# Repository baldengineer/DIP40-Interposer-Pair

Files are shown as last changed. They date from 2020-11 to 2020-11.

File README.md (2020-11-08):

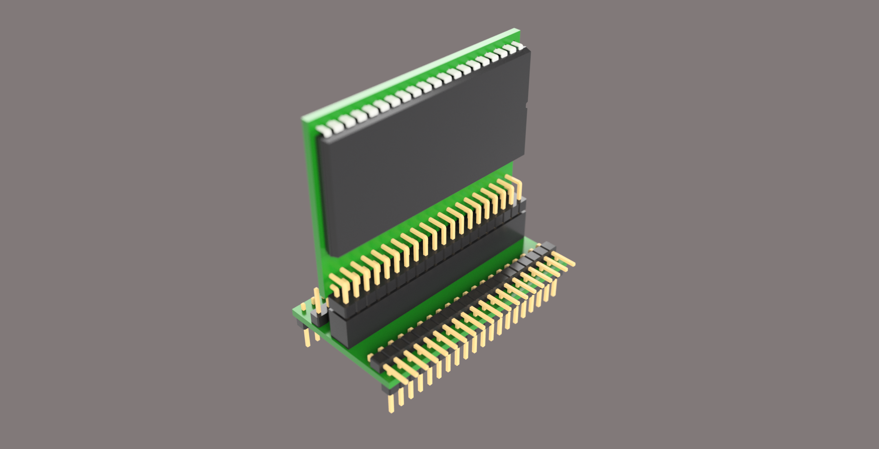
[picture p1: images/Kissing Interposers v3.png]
DIP40 interposer boards connected together

## DIP40 Interposer Board Pair
This adapter makes it easier to probe a DIP-40 (0.6" wide) chip using a logic analyzer or mixed-signal oscilloscope. The boards breakout each of the signals.

Originally this was designed to test the Z80 and ULA chips of a ZX-81. However, there is nothing chip-specific in this design.

Currently, the boards are untested and being manufactured.

## PCB-Side Board
This board plugs into the PCB or the socket on the PCB. It should have a 02x20 pin-socket in the middle facing "up". Two pin-headers go near the outside edges.

The rendered image shows right-angle and straight connectors. It is not clear yet which is a better option. Consider how your probes connect to the pins.

## Chip Carrier Board
The chip under test plugs into this board. Ideally, you probably want to use a socket to connect a 0.6" wide DIP-40 chip. Right-angled pin-headers allow for a clean mating. If you use "straight" header-pins, half of the logic probe pins are blocked.

## Bald Engineer on Twitch
This board was designed, built, and tested live with the Bald Engineer. Check out his electronics live stream at: [https://twitch.tv/baldengineer](https://twitch.tv/baldengineer).

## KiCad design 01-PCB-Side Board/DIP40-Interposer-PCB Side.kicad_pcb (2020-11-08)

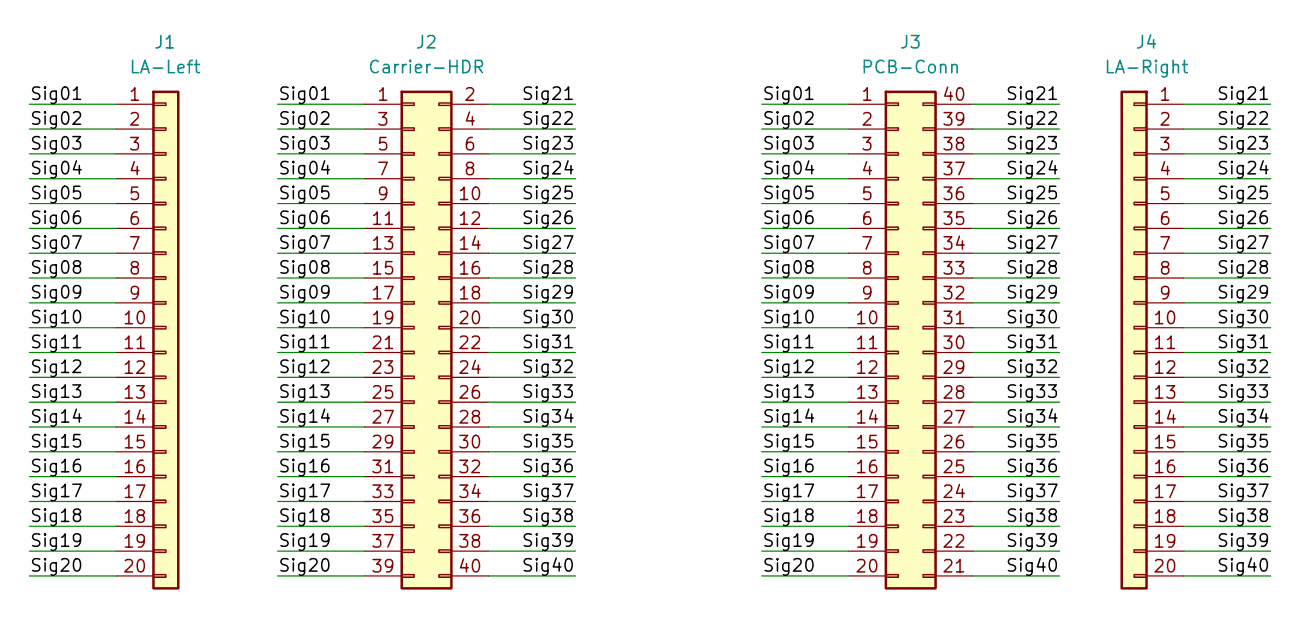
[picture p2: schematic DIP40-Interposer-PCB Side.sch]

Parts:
J1: LA-Left; PinHeader_1x20_P2.54mm_Vertical
J2: Carrier-HDR; PinSocket_2x20_P2.54mm_Vertical
J3: PCB-Conn; DIP-40_W25.4mm_Socket_LongPads
J4: LA-Right; PinHeader_1x20_P2.54mm_Vertical

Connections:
/Sig01: J1.1, J2.1, J3.1
/Sig02: J1.2, J2.3, J3.2
/Sig03: J1.3, J2.5, J3.3
/Sig04: J1.4, J2.7, J3.4
/Sig05: J1.5, J2.9, J3.5
/Sig06: J1.6, J2.11, J3.6
/Sig07: J1.7, J2.13, J3.7
/Sig08: J1.8, J2.15, J3.8
/Sig09: J1.9, J2.17, J3.9
/Sig10: J1.10, J2.19, J3.10
/Sig11: J1.11, J2.21, J3.11
/Sig12: J1.12, J2.23, J3.12
/Sig13: J1.13, J2.25, J3.13
/Sig14: J1.14, J2.27, J3.14
/Sig15: J1.15, J2.29, J3.15
/Sig16: J1.16, J2.31, J3.16
/Sig17: J1.17, J2.33, J3.17
/Sig18: J1.18, J2.35, J3.18
/Sig19: J1.19, J2.37, J3.19
/Sig20: J1.20, J2.39, J3.20
/Sig21: J2.2, J3.40, J4.1
/Sig22: J2.4, J3.39, J4.2
/Sig23: J2.6, J3.38, J4.3
/Sig24: J2.8, J3.37, J4.4
/Sig25: J2.10, J3.36, J4.5
/Sig26: J2.12, J3.35, J4.6
/Sig27: J2.14, J3.34, J4.7
/Sig28: J2.16, J3.33, J4.8
/Sig29: J2.18, J3.32, J4.9
/Sig30: J2.20, J3.31, J4.10
/Sig31: J2.22, J3.30, J4.11
/Sig32: J2.24, J3.29, J4.12
/Sig33: J2.26, J3.28, J4.13
/Sig34: J2.28, J3.27, J4.14
/Sig35: J2.30, J3.26, J4.15
/Sig36: J2.32, J3.25, J4.16
/Sig37: J2.34, J3.24, J4.17
/Sig38: J2.36, J3.23, J4.18
/Sig39: J2.38, J3.22, J4.19
/Sig40: J2.40, J3.21, J4.20

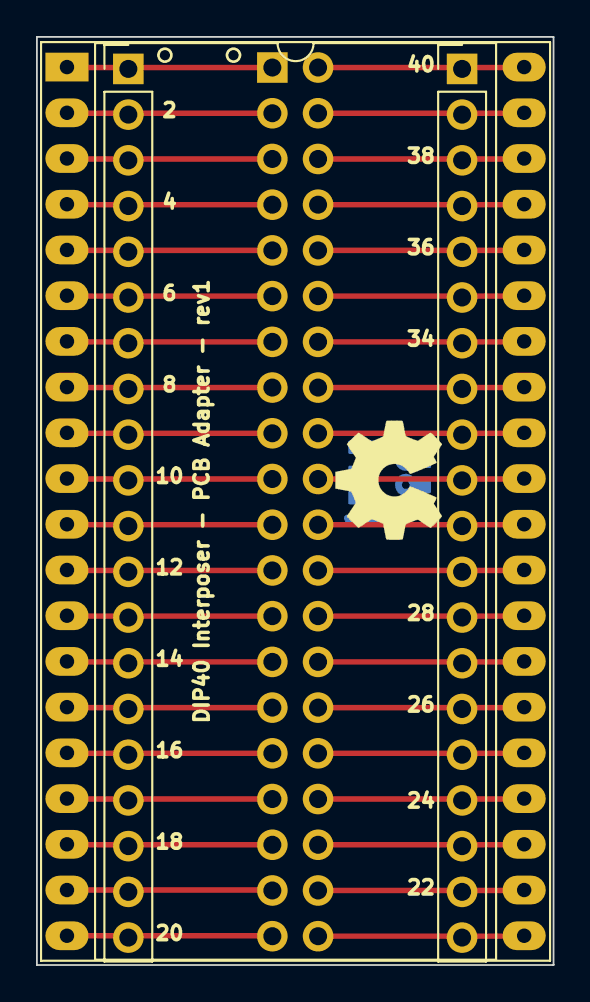
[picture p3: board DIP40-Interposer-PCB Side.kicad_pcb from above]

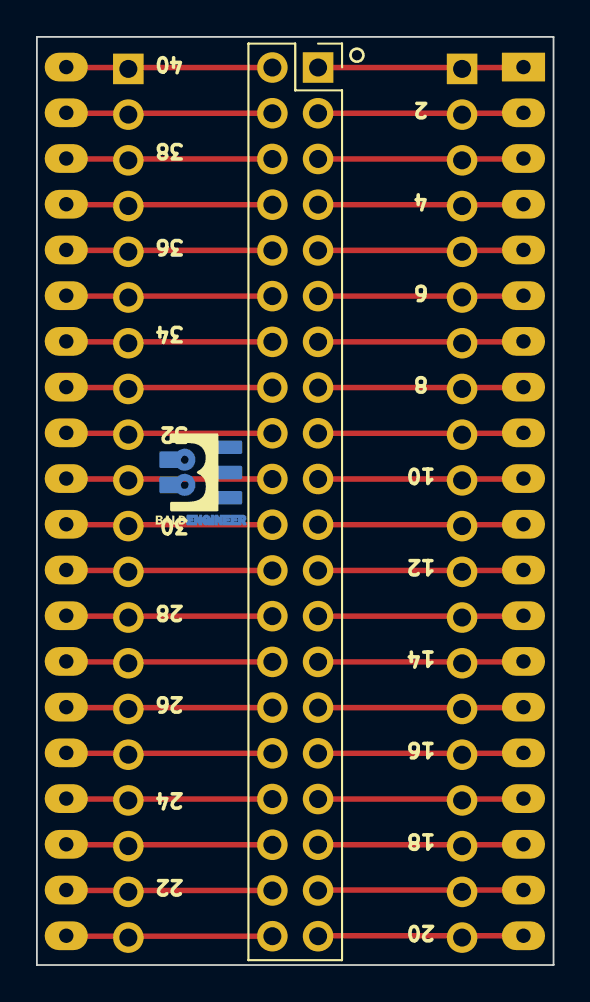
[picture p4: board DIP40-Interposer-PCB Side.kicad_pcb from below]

Board: 2 copper layers, 28.7 x 51.6 mm, 5 parts (2 on the bottom side), 40 nets.

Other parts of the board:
svg2mod: G***; BE5

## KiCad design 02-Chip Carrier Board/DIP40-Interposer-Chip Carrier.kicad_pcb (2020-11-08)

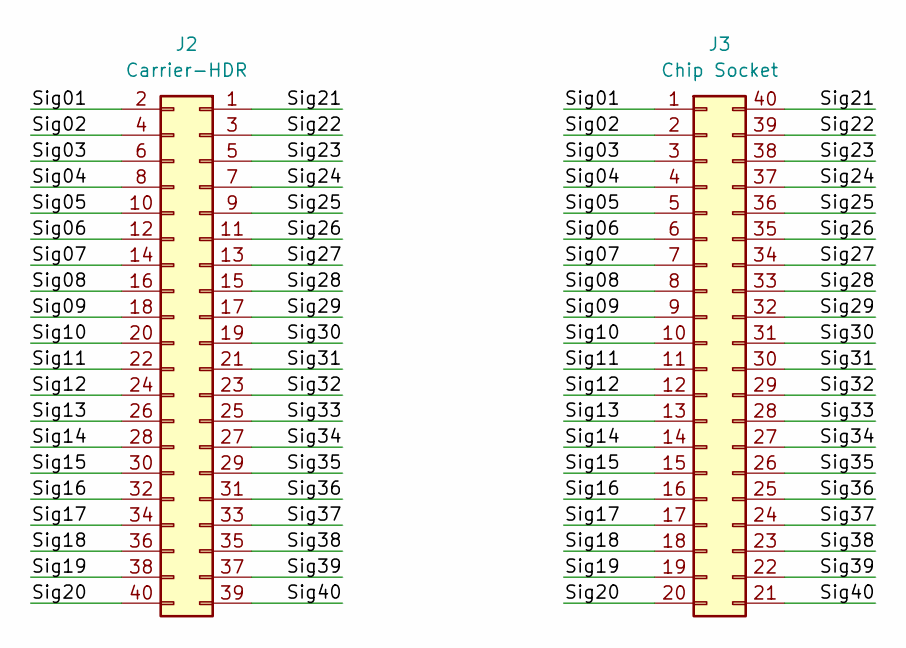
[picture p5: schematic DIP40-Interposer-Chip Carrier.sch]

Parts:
J2: Carrier-HDR; PinHeader_2x20_P2.54mm_Horizontal
J3: Chip Socket; DIP-40_W25.4mm_Socket_LongPads

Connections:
/Sig01: J2.2, J3.1
/Sig02: J2.4, J3.2
/Sig03: J2.6, J3.3
/Sig04: J2.8, J3.4
/Sig05: J2.10, J3.5
/Sig06: J2.12, J3.6
/Sig07: J2.14, J3.7
/Sig08: J2.16, J3.8
/Sig09: J2.18, J3.9
/Sig10: J2.20, J3.10
/Sig11: J2.22, J3.11
/Sig12: J2.24, J3.12
/Sig13: J2.26, J3.13
/Sig14: J2.28, J3.14
/Sig15: J2.30, J3.15
/Sig16: J2.32, J3.16
/Sig17: J2.34, J3.17
/Sig18: J2.36, J3.18
/Sig19: J2.38, J3.19
/Sig20: J2.40, J3.20
/Sig21: J2.1, J3.40
/Sig22: J2.3, J3.39
/Sig23: J2.5, J3.38
/Sig24: J2.7, J3.37
/Sig25: J2.9, J3.36
/Sig26: J2.11, J3.35
/Sig27: J2.13, J3.34
/Sig28: J2.15, J3.33
/Sig29: J2.17, J3.32
/Sig30: J2.19, J3.31
/Sig31: J2.21, J3.30
/Sig32: J2.23, J3.29
/Sig33: J2.25, J3.28
/Sig34: J2.27, J3.27
/Sig35: J2.29, J3.26
/Sig36: J2.31, J3.25
/Sig37: J2.33, J3.24
/Sig38: J2.35, J3.23
/Sig39: J2.37, J3.22
/Sig40: J2.39, J3.21

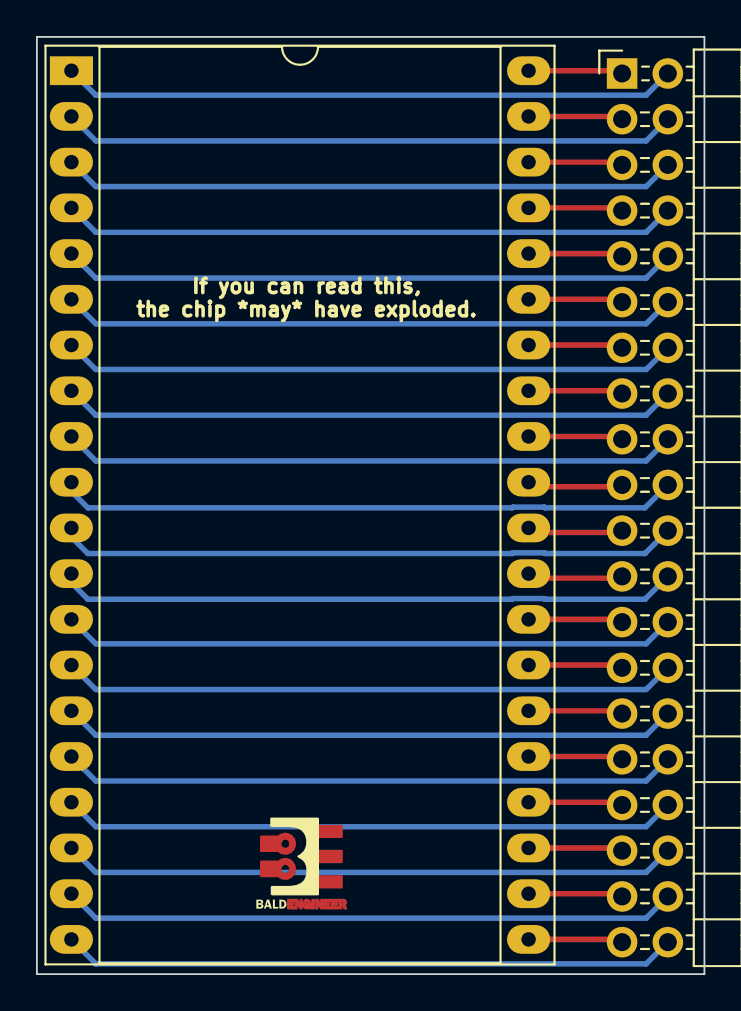
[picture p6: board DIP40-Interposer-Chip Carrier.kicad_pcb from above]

Board: 2 copper layers, 37.1 x 52.1 mm, 3 parts (0 on the bottom side), 40 nets.

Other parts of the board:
svg2mod: G***; BE5
